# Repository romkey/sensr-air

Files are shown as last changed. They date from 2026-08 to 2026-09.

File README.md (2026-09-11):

# sensr-air








Hardware design and test firmware for a small air quality sensor PCB with:

| Sensor | Function | I2C address |
|---|---|---|
| Sensirion SGP41 | VOC index / NOx index | 0x59 |
| Sensirion STCC4 | CO2 | 0x64 (0x65 if ADDR is high) |
| Sensirion SFA40 | formaldehyde (HCHO) | 0x5D |
| Sensirion SHT40 | temperature / humidity | none — connected to the STCC4's private I2C bus and read through the STCC4 |
| Bosch BMV080 | PM1 / PM2.5 / PM10 | 0x54 |

Boards up to `hw/air-stcc4/0.3.0` carry an SGP40 (VOC only) instead of the
SGP41 and have no SFA40. The two SGP parts share address 0x59; the test
firmwares read the SGP4x feature set at startup to tell them apart, so one
build runs on either revision.

This is a 3.3 V board with no voltage regulator — don't use it with 5 V
circuits. To simplify it, the board is opinionated about I2C
addresses and doesn't expose address selection pins for chips that
have them. For reliability I don't recommend putting too many chips on
one I2C bus.

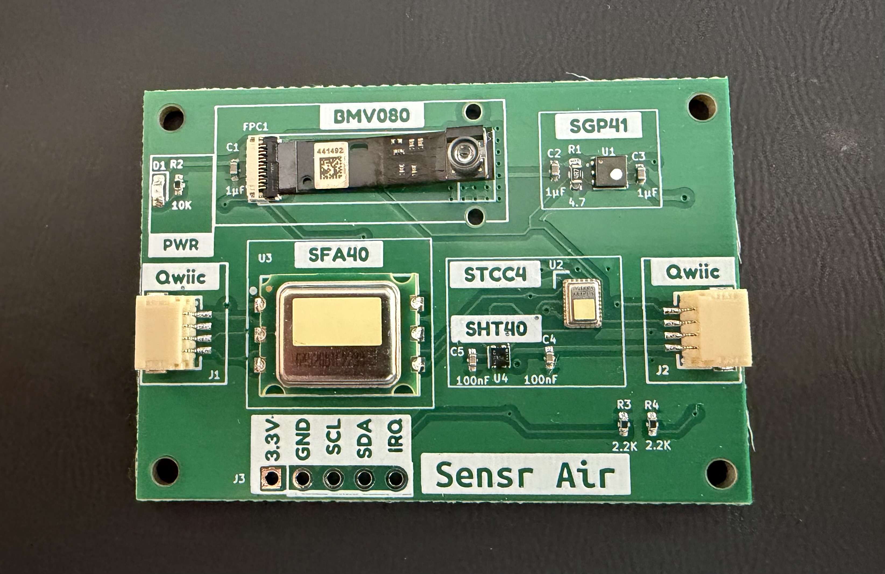
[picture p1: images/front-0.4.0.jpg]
front
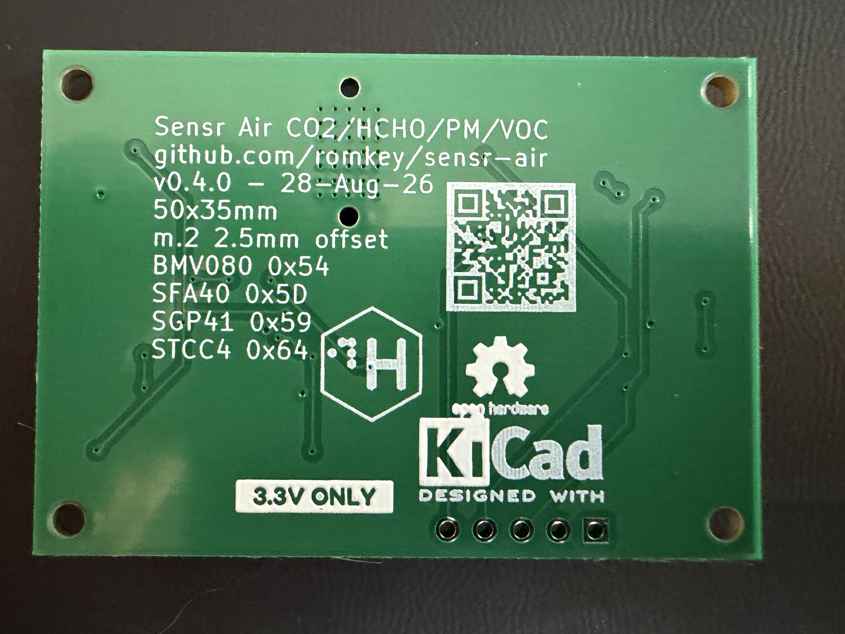
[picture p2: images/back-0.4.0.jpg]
back
 

## AI Disclosure

The board was designed by a human. CI and firmware were generated by AI.

## Hardware

Board designs live under [hw/](hw/), one subdirectory per board with a
subdirectory per version:

- [hw/air-stcc4/](hw/air-stcc4/) — STCC4 + SHT40 breakout
- [hw/air/](hw/air/) — earlier SCD40 + BME680 board

### KiCAD CI

The [KiCAD workflow](.github/workflows/kicad.yml) runs
[ci/kicad-check.sh](ci/kicad-check.sh), which runs ERC on every schematic and
DRC on every PCB of the latest version of each board under `hw/`. Only errors
fail the check; warnings are ignored. Boards or versions containing a
`.ci-kicad-ignore` file are skipped.

Run it locally with KiCAD 8+ installed:

```sh
./ci/kicad-check.sh
```

### kilint CI

The [kilint workflow](.github/workflows/kilint.yml) runs
[kilint](https://github.com/romkey/kilint), a linter for KiCAD project
conventions that ERC and DRC don't cover (title blocks, reference designators,
mounting holes, part number fields, net classes, and so on). It runs only when
[BOFFF.md](BOFFF.md) is present, and lints the single board that BOFFF.md's
`repository_path` points at via [ci/kilint-check.sh](ci/kilint-check.sh).
Older boards under `hw/` predate these conventions and are not checked.

Rule configuration lives in [.kilint.yml](.kilint.yml). kilint has no tagged
releases yet, so the workflow installs it from `main`; pin `KILINT_REF` in the
workflow once it does.

Run it locally:

```sh
pip install git+https://github.com/romkey/kilint
./ci/kilint-check.sh
```

### BOFFF

[BOFFF.md](BOFFF.md) is this board's machine-readable fabrication/form-factor
description (Bill of Form, Fit and Features) - it's a tldr; for
important facts about the board. The [BOFFF workflow](.github/workflows/bofff.yml) does nothing but
assert the file exists, so the BOFFF badge above is green whenever the repo
carries one.

## Test firmware

Each firmware directory contains a test program that exercises all of the
board's sensors, a README, and (where possible) a docker compose file to
build it. All of them print/report readings from each sensor so you can
verify a freshly assembled board.

| Directory | Platform | SGP41 | STCC4 | SFA40 | SHT40 (via STCC4) | BMV080 |
|---|---|---|---|---|---|---|
| [firmware/circuitpython/](firmware/circuitpython/) | CircuitPython 9+ | yes | yes | yes³ | yes | presence check only¹ |
| [firmware/arduino/](firmware/arduino/) | Arduino / ESP32 | yes | yes | yes | yes | yes |
| [firmware/esphome/](firmware/esphome/) | ESPHome / ESP32 | yes | yes² | yes⁴ | yes² | yes |

¹ Bosch only ships the BMV080 driver as closed-source precompiled static
libraries for specific MCU toolchains, so no CircuitPython driver exists.

² ESPHome has no upstream STCC4 support; this repo includes a local
[external component](firmware/esphome/components/stcc4/) for it.

³ Via [romkey/circuitpython-sfa40](https://github.com/romkey/circuitpython-sfa40).

⁴ ESPHome's `sfa40` component landed upstream after 2026.8, so the ESPHome
build uses the beta channel until a stable release includes it.

CI builds all three firmwares on every push
([CircuitPython](.github/workflows/circuitpython.yml),
[Arduino](.github/workflows/arduino.yml),
[ESPHome](.github/workflows/esphome.yml)).

## License

Hardware designs are licensed under the
[CERN Open Hardware Licence v2 Permissive](https://ohwr.org/cern_ohl_p_v2.txt).
Firmware is licensed under the [MIT License](https://opensource.org/license/mit).

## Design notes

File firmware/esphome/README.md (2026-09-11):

# ESPHome Test Firmware

Test firmware for the sensr-air board sensors as an ESPHome configuration,
targeting ESP32-S3 (adjust `board` and I2C pins in `sensor-test.yaml` for
your dev board).

## What it tests

| Sensor | Address | Component | Coverage |
|---|---|---|---|
| SGP41 (VOC/NOx) | 0x59 | native [`sgp4x`](https://esphome.io/components/sensor/sgp4x/) platform | VOC index + NOx index |
| STCC4 (CO2) | 0x64 | local external component ([components/stcc4](components/stcc4/)) | CO2 readings |
| SFA40 (HCHO) | 0x5D | native `sfa40` platform (ESPHome 2026.9+) | formaldehyde, temp/RH |
| SHT40 (temp/RH) | (via STCC4) | local external component | temp/RH read through the STCC4 |
| BMV080 (PM) | 0x54 | [sweitzja/esphome-bmv080](https://github.com/sweitzja/esphome-bmv080) | PM1 / PM2.5 / PM10, obstruction |

The SHT40 is not directly reachable on the I2C bus — it sits on the STCC4's
private second I2C bus, and the STCC4 reports its temperature and humidity
values as part of its measurement data.

The SFA40 measures its own temperature and humidity and uses them to
compensate the formaldehyde reading, so it reports all three.

### SGP40 or SGP41?

Boards from `hw/air-stcc4/0.4.0` on carry an SGP41 (VOC **and** NOx); earlier
boards carry an SGP40 (VOC only). You don't have to configure which: both
answer at 0x59, and the `sgp4x` component reads the sensor's feature set
(command 0x202F) at startup and logs which part it found. NOx needs an SGP41 —
on an SGP40 the component logs `SGP41 required for NOx, disabling NOx sensor`
and carries on with VOC alone, so this config works on either board.

### ESPHome version

The `sfa40` component was merged upstream after the 2026.8 release, so both
the CI workflow and `docker-compose.yml` build against the ESPHome **beta**
channel. Switch them back to `latest` once a stable release includes it.

ESPHome has no upstream STCC4 support yet, so this directory ships a small
external component in [components/stcc4](components/stcc4/) that starts
continuous measurement and reads CO2, temperature, and humidity using
Sensirion's documented I2C command set.

The BMV080 component wraps Bosch's closed-source precompiled SDK; it supports
ESP32, ESP32-S3, ESP32-C3, and ESP32-C6. It injects the SDK through
PlatformIO build flags, so the config pins `toolchain: platformio` — ESPHome's
native ESP-IDF toolchain (the default since 2026.7) doesn't honor those flags
and the build fails without it.

## Building

```sh
cp secrets.yaml.example secrets.yaml   # then edit with your Wi-Fi credentials
esphome compile sensor-test.yaml
```

Or with docker compose:

```sh
cp secrets.yaml.example secrets.yaml
docker compose run --rm compile
```

## Flashing and logs

```sh
esphome run sensor-test.yaml
```

Or with docker compose (adjust the serial device in `docker-compose.yml` if
needed):

```sh
docker compose run --rm esphome run sensor-test.yaml
```

The log output shows the I2C scan (expect devices at 0x54, 0x59, 0x5D, and
0x64) and periodic readings from all sensors.

If the STCC4's ADDR line is pulled high, change its `address` to `0x65` in
`sensor-test.yaml`.

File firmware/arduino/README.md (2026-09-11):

# Arduino Test Firmware

Test firmware for the sensr-air board sensors, targeting ESP32 boards
(default build target: ESP32-S3).

## What it tests

| Sensor | Address | Library | Coverage |
|---|---|---|---|
| SGP41 (VOC/NOx) | 0x59 | [Sensirion I2C SGP41](https://github.com/Sensirion/arduino-i2c-sgp41) | self test + raw VOC and NOx signals |
| STCC4 (CO2) | 0x64 | [Sensirion I2C STCC4](https://github.com/Sensirion/arduino-i2c-stcc4) | self test + CO2 readings |
| SFA40 (HCHO) | 0x5D | [Sensirion I2C SFA4x](https://github.com/Sensirion/arduino-i2c-sfa4x) | serial number + formaldehyde, temp/RH |
| SHT40 (temp/RH) | (via STCC4) | [Sensirion I2C STCC4](https://github.com/Sensirion/arduino-i2c-stcc4) | temp/RH read through the STCC4 |
| BMV080 (PM) | 0x54 | [DFRobot_BMV080](https://github.com/DFRobot/DFRobot_BMV080) | PM1 / PM2.5 / PM10 readings |

The SHT40 is not directly reachable on the I2C bus — it sits on the STCC4's
private second I2C bus, and the STCC4 reports its temperature and humidity
values as part of its measurement data.

### SGP40 or SGP41?

Boards from `hw/air-stcc4/0.4.0` on carry an SGP41 (VOC **and** NOx); earlier
boards carry an SGP40 (VOC only). Both answer at 0x59 and both respond to the
same serial-number command, so the sketch tells them apart the only way you
can: by issuing the SGP4x "Get Feature Set" command (0x202F) and masking the
low 9 bits of the reply — `0x0020` is an SGP40, `0x0040` an SGP41. The sketch
prints which part it found and drives it with the matching Sensirion library,
so one build works on either board.

The SGP41 needs up to 10 seconds of NOx conditioning at 1 Hz after power-up;
`SRAW_NOx` reads 0 until that finishes, and the sketch marks those lines
`(conditioning)`.

The SFA40's self-test puts the sensor into a special mode for 5–6 minutes, so
the sketch doesn't run it — it reads the serial number and starts continuous
measurement instead.

The BMV080 driver is Bosch's closed-source precompiled SDK, bundled in the
DFRobot library. It only supports Xtensa ESP32 targets (ESP32, ESP32-S2,
ESP32-S3), which is why this sketch targets ESP32.

## Wiring

Connect the sensr-air board to your ESP32 via the Qwiic/STEMMA QT connector,
or wire 3V3, GND, SDA, and SCL to the board's header. This is a 3.3 V board —
do not use 5 V.

The sketch uses the dev board's default `SDA`/`SCL` pins. To override, define
`I2C_SDA_PIN` / `I2C_SCL_PIN` at build time or edit the top of the sketch.

If the STCC4's ADDR line is pulled high, change `STCC4_ADDR` to `0x65`.

## Building with arduino-cli

```sh
arduino-cli config init --additional-urls \
    https://espressif.github.io/arduino-esp32/package_esp32_index.json
arduino-cli core update-index
arduino-cli core install esp32:esp32

arduino-cli lib install "Sensirion Core" "Sensirion I2C SGP40" \
    "Sensirion I2C SGP41" "Sensirion I2C SFA4x" "Sensirion I2C STCC4"
arduino-cli config set library.enable_unsafe_install true
arduino-cli lib install --git-url https://github.com/DFRobot/DFRobot_BMV080.git

arduino-cli compile --fqbn esp32:esp32:esp32s3 sensor-test
arduino-cli upload --fqbn esp32:esp32:esp32s3 -p /dev/ttyACM0 sensor-test
```

## Building with docker compose

```sh
docker compose run --rm build
```

The compiled firmware is written to `./build/`. Flash it with `esptool` or
`arduino-cli upload`.

## Expected output

PASS/FAIL lines for each sensor on the serial console (115200 baud), then
continuous readings every 2 seconds:

```
[PASS] SGP4x present (0x59) detected: SGP41
[PASS] STCC4 present (0x64)
[PASS] SFA40 present (0x5D)
[PASS] BMV080 present (0x54)

[PASS] SGP41 self test result: 0xd400
[PASS] STCC4 self test
[PASS] SFA40 init serial: ...
[PASS] BMV080 init id: ...

SGP41:  raw VOC 30398, raw NOx 15803
STCC4:  CO2 617 ppm | SHT40: 23.4 C, 41.2 %RH
SFA40:  HCHO 12.3 ppb | 23.6 C, 40.8 %RH (status 0x0000)
BMV080: PM1 2.1, PM2.5 3.4, PM10 4.0 ug/m3
```

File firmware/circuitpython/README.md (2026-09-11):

# CircuitPython Test Firmware

Test firmware for the sensr-air board sensors, written for CircuitPython 9+.

## What it tests

| Sensor | Address | Driver | Coverage |
|---|---|---|---|
| SGP41 (VOC/NOx) | 0x59 | [adafruit_sgp41](https://github.com/adafruit/Adafruit_CircuitPython_SGP41) | self test + raw signals + VOC/NOx index |
| STCC4 (CO2) | 0x64 | [adafruit_stcc4](https://github.com/adafruit/Adafruit_CircuitPython_STCC4) | self test + CO2 readings |
| SFA40 (HCHO) | 0x5D | [sfa40](https://github.com/romkey/circuitpython-sfa40) | serial number + formaldehyde, temp/RH |
| SHT40 (temp/RH) | (via STCC4) | [adafruit_stcc4](https://github.com/adafruit/Adafruit_CircuitPython_STCC4) | temp/RH read through the STCC4 |
| BMV080 (PM) | 0x54 | none | I2C presence check only |

The SHT40 is not directly reachable on the I2C bus — it sits on the STCC4's
private second I2C bus, and the STCC4 reports its temperature and humidity
values as part of its measurement data.

### SGP40 or SGP41?

Boards from `hw/air-stcc4/0.4.0` on carry an SGP41 (VOC **and** NOx); earlier
boards carry an SGP40 (VOC only). Both answer at 0x59 and both respond to the
same serial-number command, so the code tells them apart the only way you can:
by reading the SGP4x "Get Feature Set" command (0x202F) and masking the low 9
bits of the reply — `0x0020` is an SGP40, `0x0040` an SGP41. This is exactly
what ESPHome's `sgp4x` component does. The test prints which part it found and
loads the matching driver, so the same `code.py` works on either board.

The SGP41 needs up to 10 seconds of NOx conditioning at 1 Hz after power-up
before its first real measurement, which the test runs before it starts
printing readings. The gas index algorithm then warms up for about 45 seconds,
returning 0 for both indices until it settles.

**SFA40 self test:** the SFA40's self-test puts the sensor into a special mode
for 5–6 minutes, so this test doesn't run it. Use the driver's
`sfa40_self_test.py` example if you want to run it after assembly.

**BMV080 limitation:** Bosch only distributes the BMV080 driver as
closed-source precompiled static libraries for specific MCU toolchains, so no
CircuitPython driver exists. This test only verifies the BMV080 answers on the
I2C bus at 0x54. Use the [Arduino](../arduino/) or [ESPHome](../esphome/)
tests for actual PM readings.

## Running on hardware

1. Install CircuitPython 9+ on a board with a STEMMA QT/Qwiic connector (or
   wire the sensr-air board's SDA/SCL/3V3/GND to your board's I2C pins).
   The code prefers `board.STEMMA_I2C()` and falls back to
   `board.SCL`/`board.SDA`.
2. Install the Adafruit libraries onto the board with
   [circup](https://github.com/adafruit/circup):

   ```sh
   circup install adafruit_sgp41 adafruit_stcc4
   ```

   Add `adafruit_sgp40` too if you are testing a board older than 0.4.0.
   The SFA40 driver isn't in the Adafruit bundle, so copy its `sfa40.py` to
   the `lib` directory on the `CIRCUITPY` drive:

   ```sh
   git clone https://github.com/romkey/circuitpython-sfa40
   cp circuitpython-sfa40/sfa40.py /Volumes/CIRCUITPY/lib/
   ```

3. Copy `code.py` to the `CIRCUITPY` drive.
4. Watch the serial console. You should see PASS lines for each sensor
   followed by continuous readings every 2 seconds.

If the STCC4's ADDR line is pulled high, change `STCC4_ADDR` to `0x65` at the
top of `code.py`.

## Build check

CircuitPython is interpreted, so the "build" is a compile check with
`mpy-cross` (this is what CI runs):

```sh
pip install mpy-cross
mpy-cross code.py -o /tmp/code.mpy
```

Or with docker compose:

```sh
docker compose run --rm build
```

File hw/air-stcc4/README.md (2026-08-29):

# Sensr Air STCC4

This breakout board has Sensirion's new CO2 sensor, the STCC4, as well as an SHT40 temperature/humidity sensor. The board also has two STEMMAQT/Qwiic connectors and a five pin header with power, I2C and the STCC4's address select pin.

This is a 3.3V board and has no voltage regulator, so don't use it with 5V circuits!

It also has a power LED.

The STCC4 has a selectable I2C address depending on the state of the ADDR line.  The ADDR line has a weak pulldown resistor so that the STCC4's default I2C address is 0x64. If ADDR is high, the address will be 0x65.

The SHT40 is not directly accessible from the I2C bus. Instead it connects to a private second I2C bus with the STCC4. Its values may be read through the STCC4.

## 0.1.0 Hardware

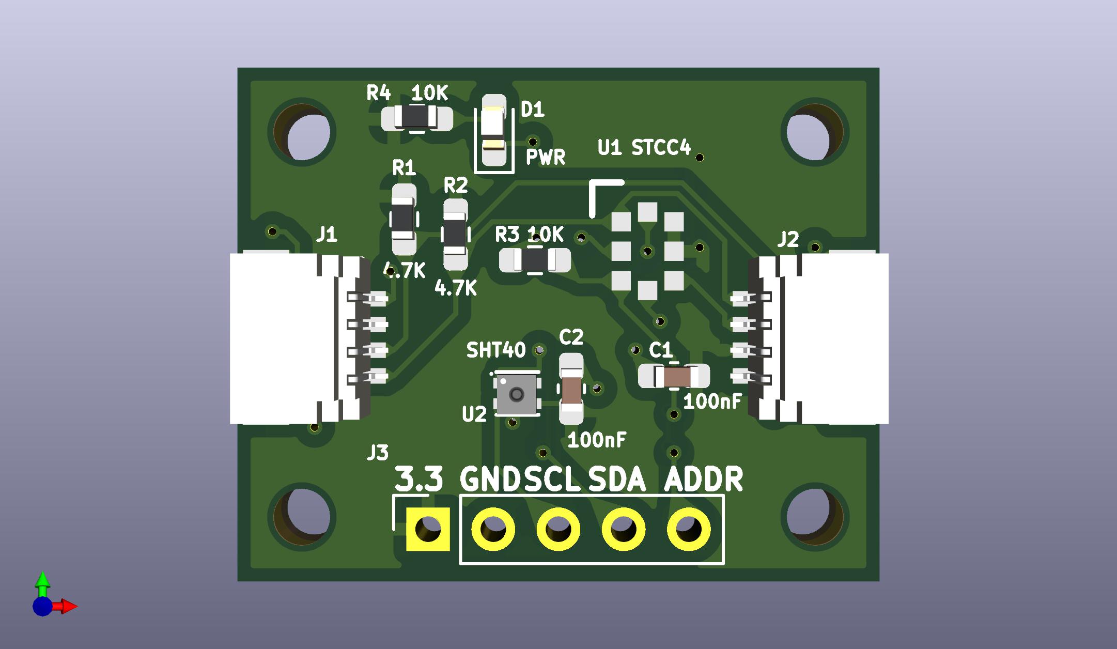
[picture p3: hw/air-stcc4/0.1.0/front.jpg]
front


## Firmware

Example program in CircuitPython:

```
import time
import board
import busio
from adafruit_stcc4 import STCC4

# Initialize I2C bus
i2c = busio.I2C(board.SCL, board.SDA)

# Initialize STCC4 sensor
sensor = STCC4(i2c)

print("STCC4 CO2 Sensor Test")
print("=" * 50)

# Print sensor information
print(f"Serial Number: {sensor.serial_number}")
print(f"Firmware Version: {sensor.firmware_version[0]}.{sensor.firmware_version[1]}")
print(f"SHT40 Available: {sensor.sht40_available}")
print()

# Read CO2, temperature, and humidity measurements
print("Environmental Measurements:")
print("-" * 30)

while True:
    co2 = sensor.co2
    print(f"Reading {i+1:2d}: CO2: {co2:6.1f} ppm")
        
    if sensor.sht40_available:
       temperature, humidity = sensor.measure_temperature_humidity()
       print(f"           Temp: {temperature:5.1f}°C, Humidity: {humidity:5.1f}%")
    else:
       print("           SHT40 not available - no temp/humidity data")
        
    print()
        
    time.sleep(2)  # Wait 2 seconds between readings

print("Test complete!")
```

## License

Please see the top level [README](../../README.md) for license information.

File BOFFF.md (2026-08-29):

---
bofff_version: 1
board:
  name: Sensr Air CO2/HCHO/PM/VOC
  version: 0.4.0
  date: '2026-08-28'
  organization: PDX Hackerspace
  license: CERN-OHL-S
  repository: https://github.com/romkey/sensr-air
  repository_path: hw/air-stcc4/0.4.0
  notes:
  - John Romkey
  - 'License: CERN-OHL-S https://ohwr.org/cern_ohl_s_v2.pdf'
source_files:
  ecad: KiCad
  project: air-stcc4.kicad_pro
  schematic: air-stcc4.kicad_sch
  pcb: air-stcc4.kicad_pcb
  step: null
  dxf: null
  bom: null
form:
  units: mm
  origin: top-left of bounding box, x right, y down
  outline:
    shape: rectangle
    width: 50
    height: 35
  thickness: 1.6
  copper_layers: 2
  max_height_top: null
  max_height_bottom: null
mounting:
  holes:
  - ref: MNT1
    x: 2.5
    y: 2.5
    diameter: 2.2
  - ref: MNT2
    x: 47.5
    y: 2.5
    diameter: 2.2
  - ref: MNT3
    x: 2.5
    y: 32.5
    diameter: 2.2
  - ref: MNT4
    x: 47.5
    y: 32.5
    diameter: 2.2
power:
  rails:
  - net: GND
    kind: ground
    connections: 14
  - net: +3.3V
    kind: supply
    connections: 16
  usb:
    present: false
  battery:
    present: false
  input_voltage: null
  current_typical: null
  current_peak: null
connectors:
- ref: FPC1
  part: 046844713002846+_C5857733
  footprint: easyeda2kicad:FPC-SMD_13P-P0.60_046844713002846-1
  x: 10.555
  y: 7.124
  populated: true
  pins:
  - pad: '2'
    net: /BV_IRQ
  - pad: '3'
    net: GND
  - pad: '4'
    net: +3.3V
  - pad: '5'
    net: GND
  - pad: '6'
    net: +3.3V
  - pad: '7'
    net: +3.3V
  - pad: '8'
    net: /SCL
  - pad: '9'
    net: /SDA
  - pad: '10'
    net: GND
  - pad: '11'
    net: +3.3V
  - pad: '12'
    net: GND
  - pad: '13'
    net: +3.3V
  - pad: '14'
    net: GND
  - pad: '15'
    net: GND
- ref: J1
  part: BM04B-SRSS-TB(LF)(SN)
  footprint: easyeda2kicad:CONN-SMD_4P-P1.00_SM04B-SRSS-TB-LF-SN
  x: 3.5
  y: 21
  populated: true
  pins:
  - pad: '1'
    net: GND
  - pad: '2'
    net: +3.3V
  - pad: '3'
    net: /SDA
  - pad: '4'
    net: /SCL
  - pad: '5'
    net: GND
  - pad: '6'
    net: GND
- ref: J2
  part: BM04B-SRSS-TB(LF)(SN)
  footprint: easyeda2kicad:CONN-SMD_4P-P1.00_SM04B-SRSS-TB-LF-SN
  x: 46.31
  y: 21
  populated: true
  pins:
  - pad: '1'
    net: GND
  - pad: '2'
    net: +3.3V
  - pad: '3'
    net: /SDA
  - pad: '4'
    net: /SCL
  - pad: '5'
    net: GND
  - pad: '6'
    net: GND
- ref: J3
  part: Conn_01x08
  footprint: Connector_PinSocket_2.54mm:PinSocket_1x05_P2.54mm_Vertical
  x: 11.42
  y: 33
  populated: false
  pins:
  - pad: '1'
    net: +3.3V
  - pad: '2'
    net: GND
  - pad: '3'
    net: /SCL
  - pad: '4'
    net: /SDA
  - pad: '5'
    net: /BV_IRQ
interfaces:
  i2c:
  - name: primary
    nets:
    - /SCL
    - /SDA
    pullups:
    - ref: R4
      line: SCL
      net: /SCL
      pulls_to: +3.3V
      voltage: 3.3
      value: 2.2K
      resistance: 2200
    - ref: R3
      line: SDA
      net: /SDA
      pulls_to: +3.3V
      voltage: 3.3
      value: 2.2K
      resistance: 2200
    devices:
    - ref: U1
      part: SGP41
      address: '0x59'
    - ref: U2
      part: STCC4
      address: '0x64'
    - ref: U3
      part: SFA40-D-R1
      address: '0x5D'
    exposed_on:
    - FPC1
    - J1
    - J2
    - J3
  - name: _c
    nets:
    - /SCL_C
    - /SDA_C
    pullups: null
    devices:
    - ref: U2
      part: STCC4
      address: '0x64'
    - ref: U4
      part: SHT40
      address: '0x44'
    exposed_on: null
---

# Sensr Air CO2/HCHO/PM/VOC — BOFFF

**BOFFF** — a Bill Of Form, Fit and Function. A summary of this
board's physical and electrical facts for anyone designing an
enclosure, a mount, or a mating board.

- **Form** — outline, thickness, layer count.
- **Fit** — mounting holes and connector positions.
- **Function** — power rails and the buses the board exposes.

## Coordinates

Millimetres. The origin is the **top-left corner of the board
outline's bounding box**, with X increasing right and Y increasing
**down**. This is the opposite of the usual mathematical
convention and is the most likely source of a silent error in
anything consuming this file.

## Generated, not authored

Everything above was extracted from the KiCad files listed under
`source_files`. Regenerate it rather than editing it by hand:

```bash
kilint bofff . > BOFFF.md
```

For exact geometry — curves, slots, internal cutouts, component
heights — use the STEP/DXF exports rather than this summary. A
bounding box is not an outline.

## Complete by hand

These are not recorded in the KiCad files and are emitted as
`null`. They need a human:

- `form.max_height_top` — tallest component above the board; from the 3D models, not the PCB
- `form.max_height_bottom` — tallest component below the board; same
- `power.input_voltage` — the operating range; the netlist does not say
- `power.current_typical` — a measurement
- `power.current_peak` — a measurement
- `source_files.step` — path to the 3D export, once you make one
- `source_files.dxf` — path to the 2D outline export, once you make one
- `source_files.bom` — path to the exported BOM

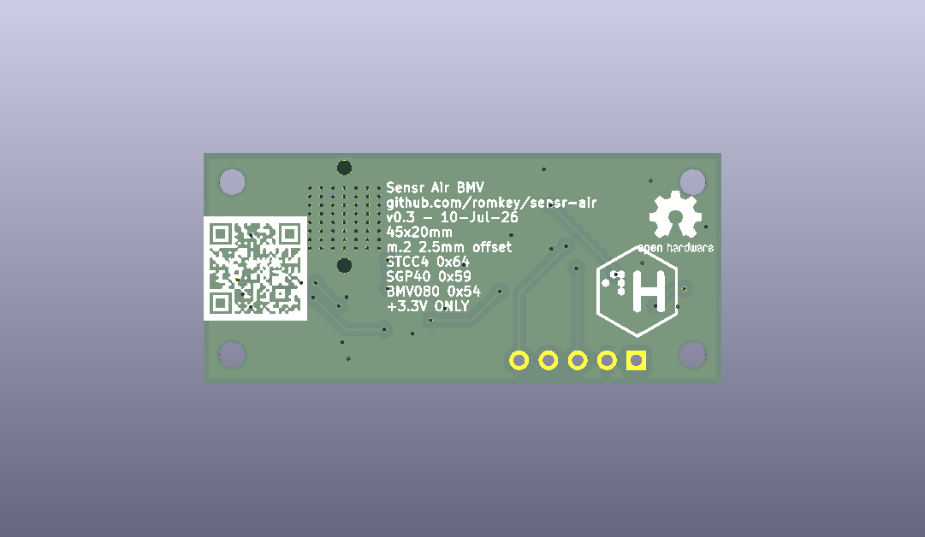
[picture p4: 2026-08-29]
images/back.png

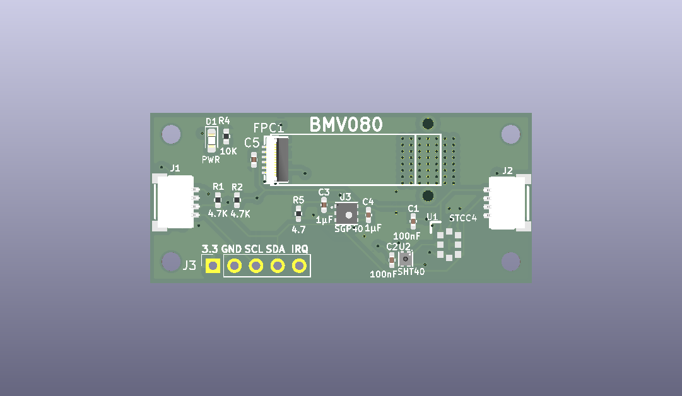
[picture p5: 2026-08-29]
images/front.png

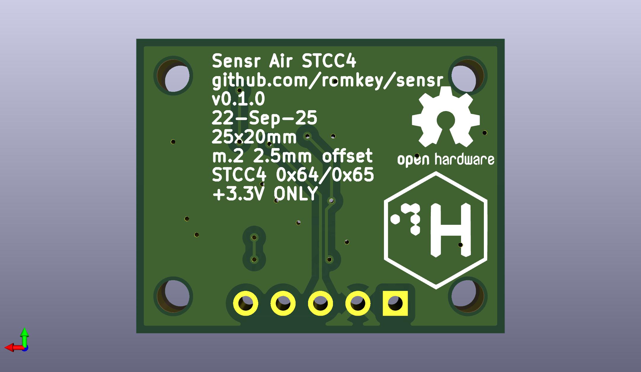
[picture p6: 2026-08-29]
hw/air-stcc4/0.1.0/back.jpg

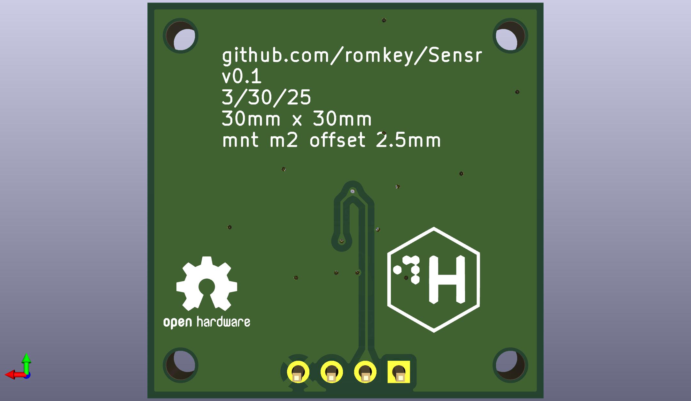
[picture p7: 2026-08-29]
hw/air/0.2/back.jpg

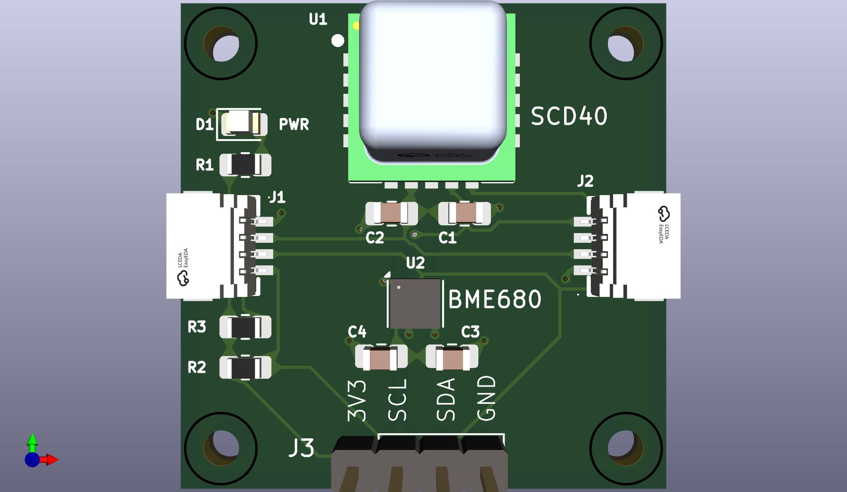
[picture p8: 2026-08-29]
hw/air/0.2/front.jpg

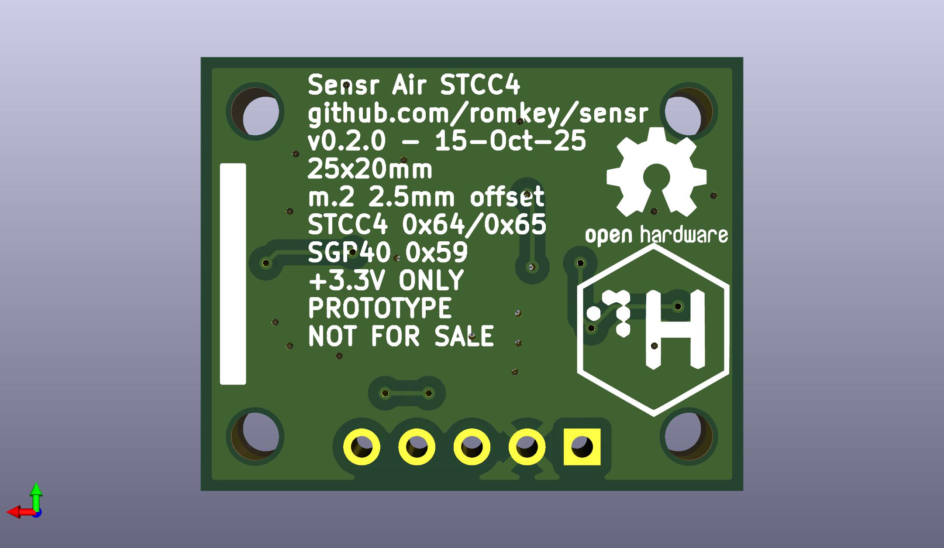
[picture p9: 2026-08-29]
hw/air-stcc4/0.2.0/back.jpg

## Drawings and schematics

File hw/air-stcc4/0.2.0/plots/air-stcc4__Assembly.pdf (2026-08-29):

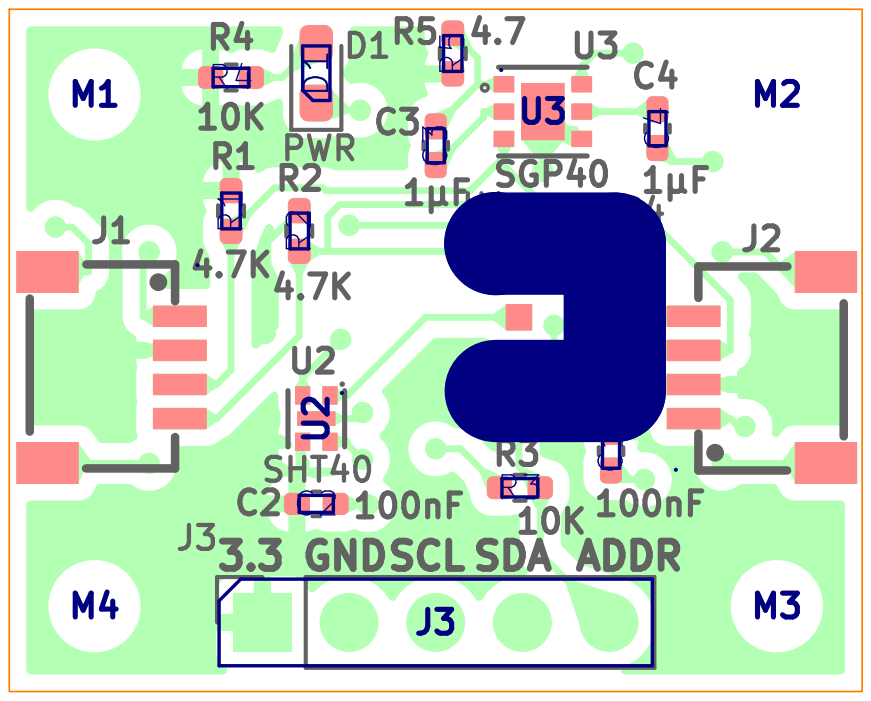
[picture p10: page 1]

Id: /1 Title: Sensr Air STCC4

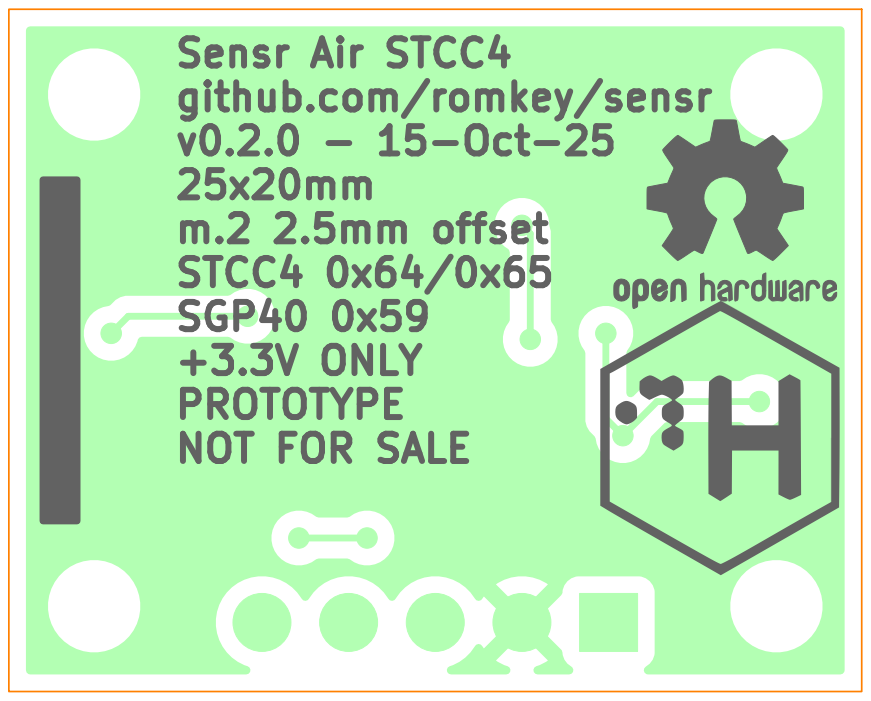
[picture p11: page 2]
Sensr Air STCC4 github.com/romkey/sensr v0.2.0 -; 15-Oct-25; m.2 2.5mm offset STCC4 0x64/0x65 SGP40 0x59 +3.3V; ONLY; PROTOTYPE NOT FOR SALE 1; D Date: 2025-10-15 KiCad; E.D.A. 9.0.4 Size: A4; Rev: 0.2.0; File: air-stcc4.kicad_pcb Sheet: Colored; BOT PDX; Hackerspace; John; Romkey License: CERN-OHL-S; https://ohwr.org/cern_ohl_s_v2.pdf PROTOTYPE -; NOT; FOR SALE; Board2Pdf:; Colored; BOT -; Page 2/2

Id: /1 Title: Sensr Air STCC4

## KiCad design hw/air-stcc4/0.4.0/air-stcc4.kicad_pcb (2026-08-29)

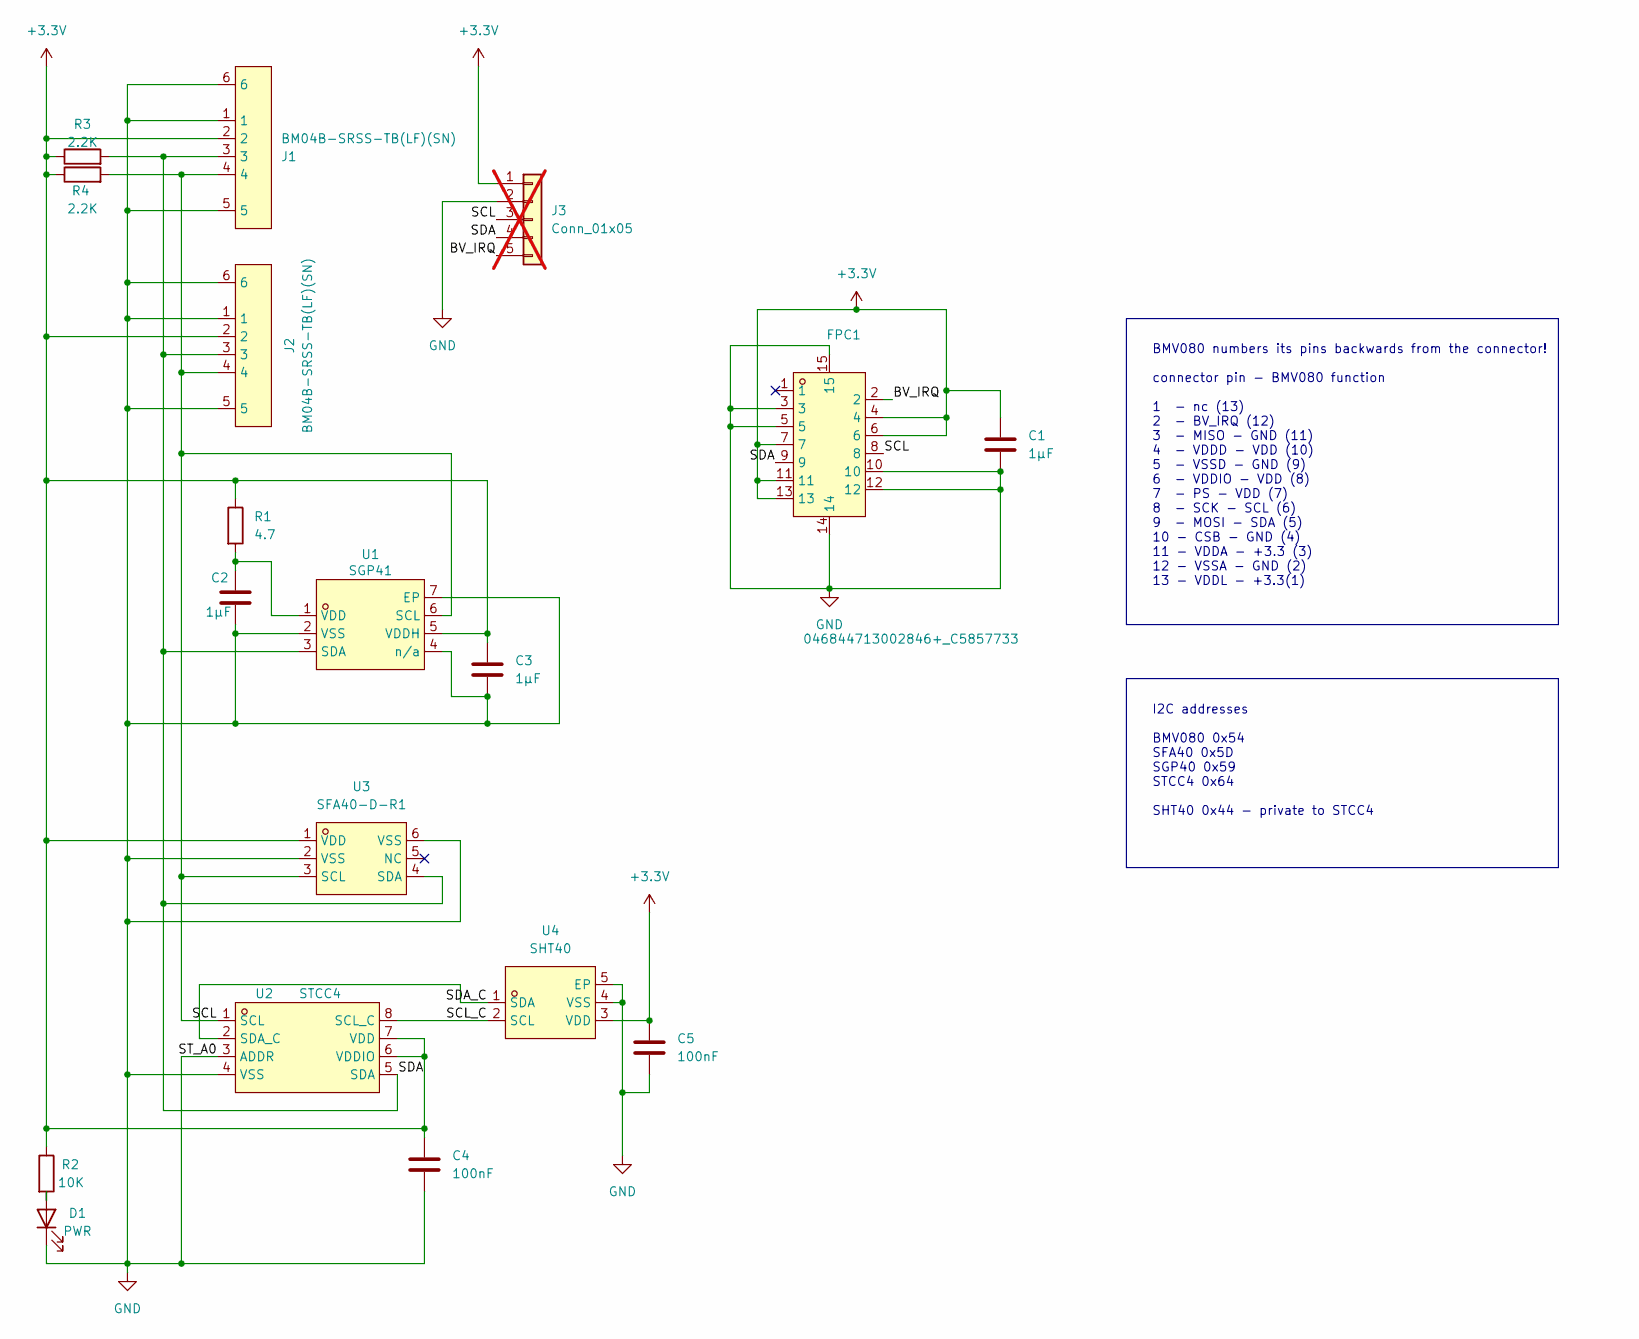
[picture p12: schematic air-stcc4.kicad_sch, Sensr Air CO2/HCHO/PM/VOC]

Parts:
C1, C2, C3: 1µF; C_0402_1005Metric_Pad0.74x0.62mm_HandSolder; LCSC Part C52923
C4, C5: 100nF; C_0402_1005Metric_Pad0.74x0.62mm_HandSolder; LCSC Part C1525
D1: PWR; LED_0603_1608Metric_Pad1.05x0.95mm_HandSolder; LCSC Part C2286
FPC1: 046844713002846+_C5857733; FPC-SMD_13P-P0.60_046844713002846-1; LCSC Part C5857733
J1, J2: BM04B-SRSS-TB(LF)(SN); CONN-SMD_4P-P1.00_SM04B-SRSS-TB-LF-SN; LCSC Part C160404
J3: Conn_01x05; PinSocket_1x05_P2.54mm_Vertical; not fitted
R1: 4.7; R_0603_1608Metric_Pad0.98x0.95mm_HandSolder; LCSC Part C23164
R2: 10K; R_0402_1005Metric_Pad0.72x0.64mm_HandSolder; LCSC Part C25744
R3, R4: 2.2K; R_0402_1005Metric_Pad0.72x0.64mm_HandSolder; LCSC Part C25879
U1: SGP41; DFN-6_L2.4-W2.4-P0.80-TL-EP; LCSC Part C3659325
U2: STCC4; LAG-8_L4.0-W3.0-P1.15-TL; LCSC Part C49191471
U3: SFA40-D-R1; SENSOR-SMD_SFA40-D-R1; LCSC Part C54863645
U4: SHT40; DFN-4_L1.5-W1.5-P0.80-TL-EP; LCSC Part C2848306

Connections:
+3.3V: C1.1, C3.1, C4.1, C5.1, FPC1.4, FPC1.6, FPC1.7, FPC1.11, FPC1.13, J1.2, J2.2, J3.1, R1.1, R2.1, R3.1, R4.1, U1.5 (VDDH), U2.6 (VDDIO), U2.7 (VDD), U3.1 (VDD), U4.3 (VDD)
/BV_IRQ: FPC1.2, J3.5
/SCL: FPC1.8, J1.4, J2.4, J3.3, R4.2, U1.6 (SCL), U2.1 (SCL), U3.3 (SCL)
/SCL_C: U2.8 (SCL_C), U4.2 (SCL)
/SDA: FPC1.9, J1.3, J2.3, J3.4, R3.2, U1.3 (SDA), U2.5 (SDA), U3.4 (SDA)
/SDA_C: U2.2 (SDA_C), U4.1 (SDA)
GND: C1.2, C2.2, C3.2, C4.2, C5.2, D1.1 (K), FPC1.3, FPC1.5, FPC1.10, FPC1.12, FPC1.14, FPC1.15, J1.1, J1.5, J1.6, J2.1, J2.5, J2.6, J3.2, U1.2 (VSS), U1.4 (n/a), U1.7 (EP), U2.3 (ADDR), U2.4 (VSS), U3.2 (VSS), U3.6 (VSS), U4.4 (VSS), U4.5 (EP)
unnamed: D1.2 (A), R2.2
unnamed: C2.1, R1.2, U1.1 (VDD)

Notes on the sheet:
BMV080 numbers its pins backwards from the connector! connector pin - BMV080 function 1 - nc (13) 2 - BV_IRQ (12) 3 - MISO - GND (11) 4 - VDDD - VDD (10) 5 - VSSD - GND (9) 6 - VDDIO - VDD (8) 7 - PS - VDD (7) 8 - SCK - SCL (6) 9 - MOSI - SDA (5) 10 - CSB - GND (4) 11 - VDDA - +3.3 (3) 12 - VSSA - 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
I2C addresses BMV080 0x54 SFA40 0x5D SGP40 0x59 STCC4 0x64 SHT40 0x44 - private to STCC4

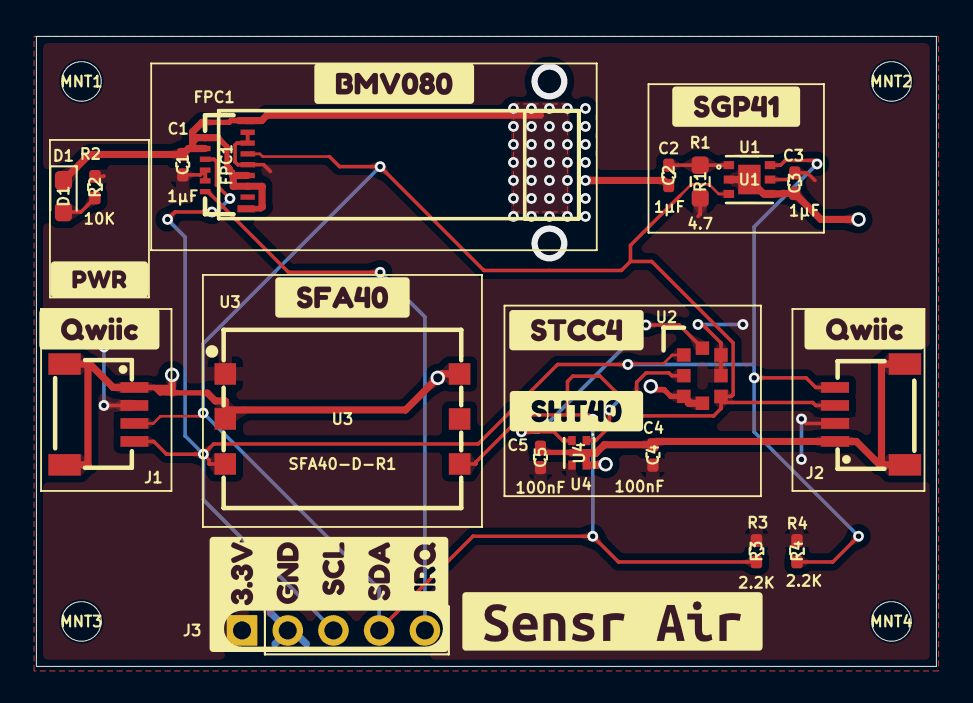
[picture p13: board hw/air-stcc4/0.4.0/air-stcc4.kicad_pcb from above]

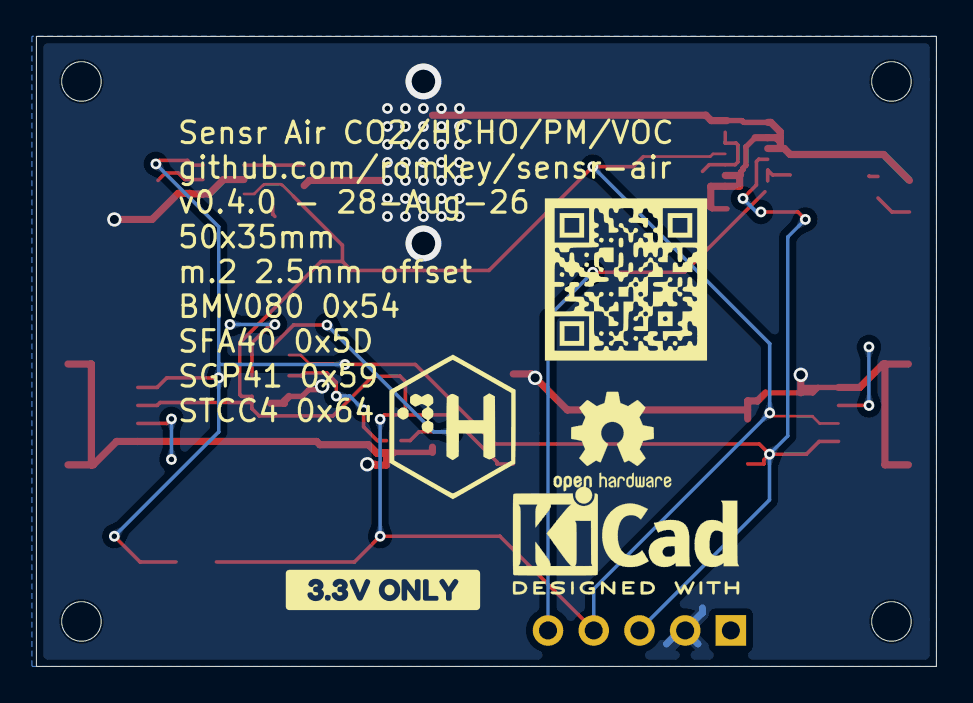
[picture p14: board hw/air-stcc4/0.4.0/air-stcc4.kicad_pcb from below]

Board: 2 copper layers, 50.0 x 35.0 mm, 37 parts (5 on the bottom side), 9 nets.

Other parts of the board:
GRPH1: LOGO
GRPH2: CTRLH Logo
GRPH3: OSHW-Logo2_7.3x6mm_SilkScreen
GRPH4: KiCad-Logo2_5mm_SilkScreen
MNT1, MNT2, MNT3, MNT4: MountingHole_2.2mm_M2
kobee-studio-1: GRPH4; kobee-studio-6A887D6C
kobee-studio-2: GRPH5; kobee-studio-6A887DEC
kobee-studio-3: G***; kobee-studio-6A91A728
kobee-studio-4: GRPH8; kobee-studio-6A887E41
kobee-studio-5: GRPH7; kobee-studio-6A887E5F
kobee-studio-6: GRPH9; kobee-studio-6A887E13
kobee-studio-6A91B03A: G***; kobee-studio-6A91B03A
kobee-studio-7: GRPH6; kobee-studio-6A8882DF
kobee-studio-8: GRPH10; kobee-studio-6A887E32
kobee-studio-9: G***; kobee-studio-6A91A7CE
kobee-studio-10: GRPH11; kobee-studio-6A887EAF

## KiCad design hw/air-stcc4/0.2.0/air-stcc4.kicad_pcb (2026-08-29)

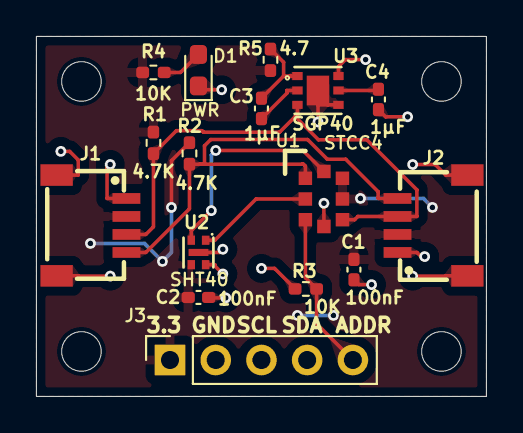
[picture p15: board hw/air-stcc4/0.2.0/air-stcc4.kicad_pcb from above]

Board: 2 copper layers, 25.0 x 20.0 mm, 21 parts (1 on the bottom side), 11 nets.

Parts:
C1, C2: 100nF; C_0402_1005Metric_Pad0.74x0.62mm_HandSolder
C3, C4: 1µF; C_0402_1005Metric_Pad0.74x0.62mm_HandSolder
D1: PWR; LED_0603_1608Metric_Pad1.05x0.95mm_HandSolder
GRPH1: CTRLH Logo
J1, J2: BM04B-SRSS-TB(LF)(SN); CONN-SMD_4P-P1.00_SM04B-SRSS-TB-LF-SN
J3: Conn_01x05; PinSocket_1x05_P2.54mm_Vertical
M1, M2, M3, M4: MountingHole_2.2mm_M2
R1, R2: 4.7K; R_0402_1005Metric_Pad0.72x0.64mm_HandSolder
R3, R4: 10K; R_0402_1005Metric_Pad0.72x0.64mm_HandSolder
R5: 4.7; R_0402_1005Metric_Pad0.72x0.64mm_HandSolder
U1: STCC4; LAG-8_L4.0-W3.0-P1.15-TL
U2: SHT40; DFN-4_L1.5-W1.5-P0.80-TL-EP
U3: SGP40; DFN-6_L2.4-W2.4-P0.80-TL-EP

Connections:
+3.3V: C1.1, C2.1, J1.2, J2.2, J3.1, R1.1, R2.1, R4.1, R5.1, U1.6 (VDDIO), U1.7 (VDD), U2.3 (VDD)
/ADDR: J3.5, R3.1, U1.3 (ADDR)
/SCL_C: U1.8 (SCL_C), U2.2 (SCL)
/SDA_C: U1.2 (SDA_C), U2.1 (SDA)
GND: C1.2, C2.2, C4.2, D1.1 (K), J1.1, J1.5, J1.6, J2.1, J2.5, J2.6, J3.2, R3.2, U1.4 (VSS), U2.4 (VSS), U2.5 (EP), U3.4 (n/a), U3.6 (SCL), U3.7 (GND)
unnamed: D1.2 (A), R4.2
unnamed: J1.4, J2.4, R2.2, U1.1 (SCL)
unnamed: J1.3, J2.3, R1.2, U1.5 (SDA), U3.3 (SDA)
unnamed: C3.1, R5.2, U3.1 (VDD)
unnamed: C4.1, U3.5 (VDDH)
unnamed: C3.2, U3.2 (VSS)

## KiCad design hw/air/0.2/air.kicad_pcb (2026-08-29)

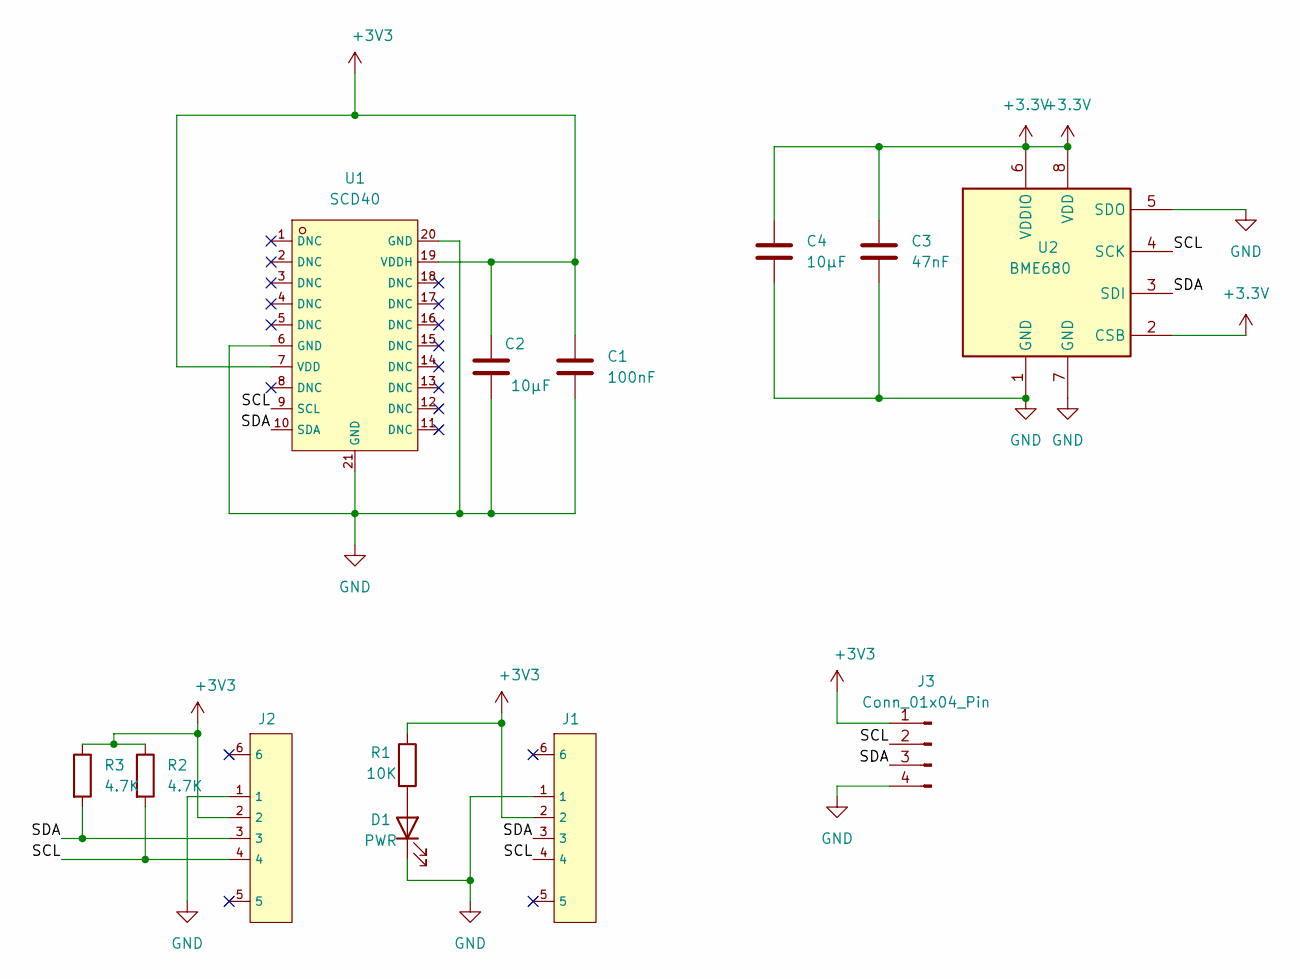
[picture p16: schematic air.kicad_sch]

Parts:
C1: 100nF; C_0805_2012Metric_Pad1.18x1.45mm_HandSolder; MPN C1711
C2, C4: 10µF; C_0805_2012Metric_Pad1.18x1.45mm_HandSolder; MPN C342724
C3: 47nF; C_0805_2012Metric_Pad1.18x1.45mm_HandSolder; MPN C1745
D1: PWR; LED_0805_2012Metric; LCSC C84256
J1, J2: SM04B-SRSS-TB_(LF)(SN); CONN-SMD_4P-P1.00_SM04B-SRSS-TB-LF-SN; LCSC C160404
J3: Conn_01x04_Pin; PinHeader_1x04_P2.54mm_Vertical
R1: 10K; R_0805_2012Metric_Pad1.20x1.40mm_HandSolder; LCSC C17414
R2, R3: 4.7K; R_0805_2012Metric_Pad1.20x1.40mm_HandSolder; MPN C105427
U1: SCD40; LGA-20_L10.1-W10.1-P1.25-TL; LCSC C3659421
U2: BME680; Bosch_LGA-8_3x3mm_P0.8mm_ClockwisePinNumbering; MPN C125972

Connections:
+3.3V: C3.1, C4.1, U2.2 (CSB), U2.6 (VDDIO), U2.8 (VDD)
+3V3: C1.1, C2.1, J1.2, J2.2, J3.1, R1.1, R2.1, R3.1, U1.7 (VDD), U1.19 (VDDH)
/SCL: J1.4, J2.4, J3.2, R2.2, U1.9 (SCL), U2.4 (SCK)
/SDA: J1.3, J2.3, J3.3, R3.2, U1.10 (SDA), U2.3 (SDI)
GND: C1.2, C2.2, C3.2, C4.2, D1.1 (K), J1.1, J2.1, J3.4, U1.6 (GND), U1.20 (GND), U1.21 (GND), U2.1 (GND), U2.5 (SDO), U2.7 (GND)
unnamed: D1.2 (A), R1.2

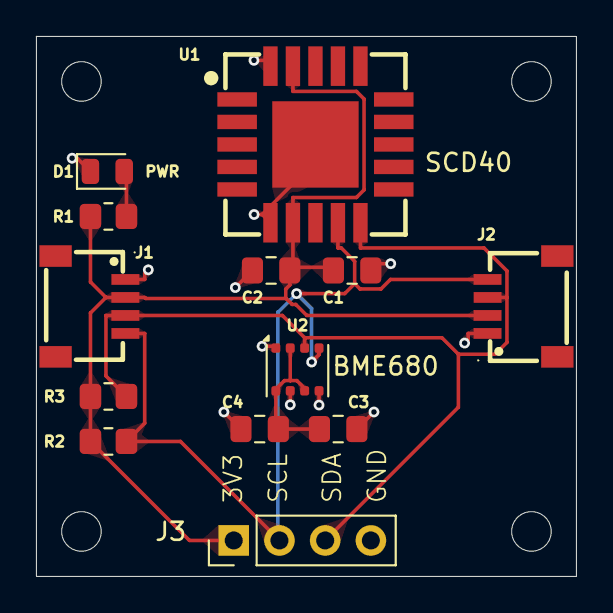
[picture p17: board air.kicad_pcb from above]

Board: 2 copper layers, 30.0 x 30.0 mm, 17 parts (0 on the bottom side), 6 nets.

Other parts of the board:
M1, M2, M3, M4: MountingHole_2.2mm_M2

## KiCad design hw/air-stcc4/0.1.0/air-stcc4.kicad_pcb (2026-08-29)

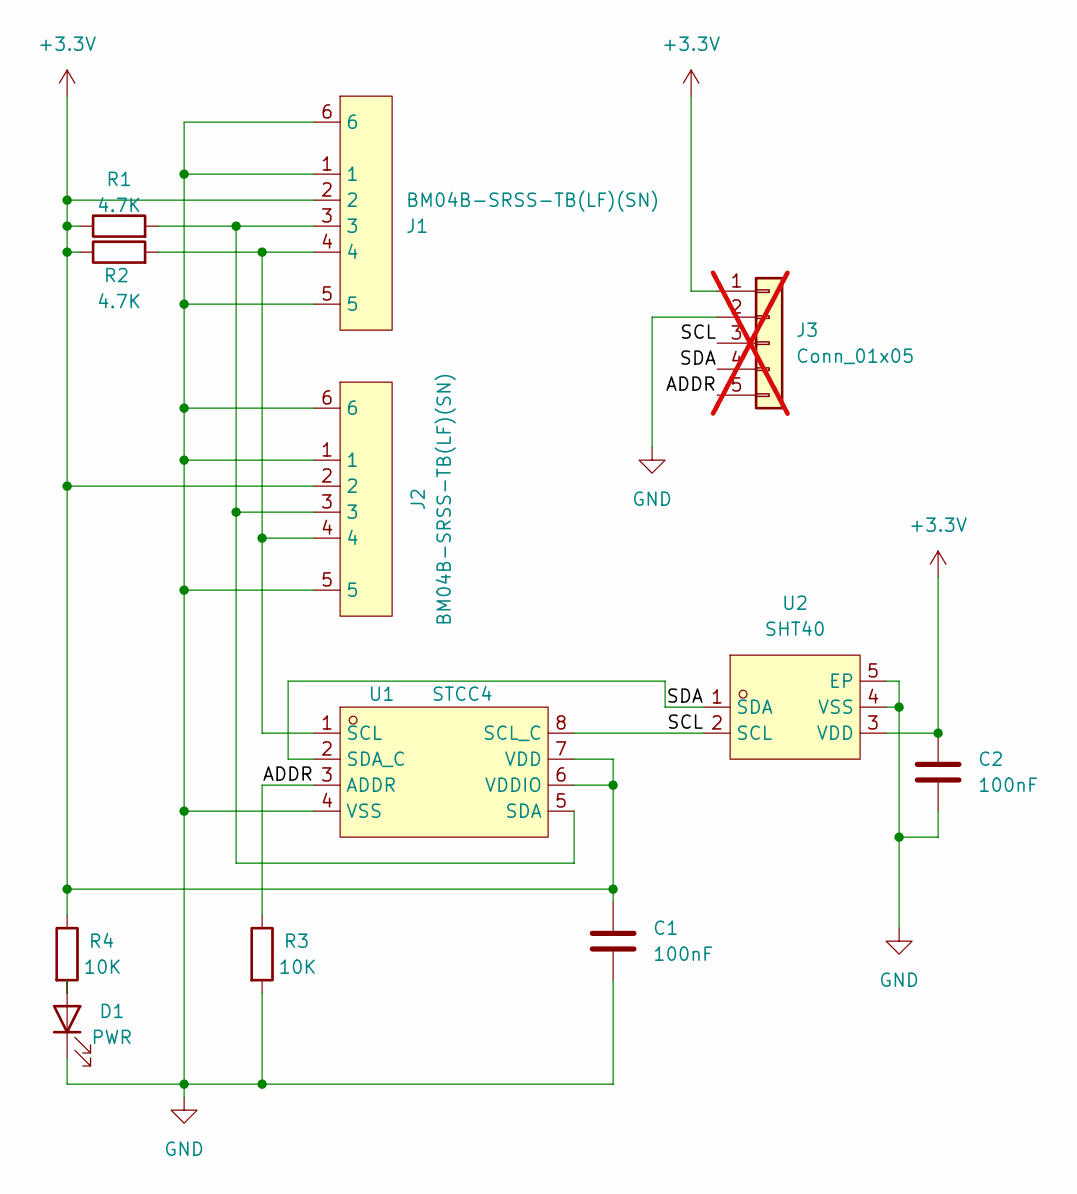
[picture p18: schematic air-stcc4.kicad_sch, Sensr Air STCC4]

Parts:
C1, C2: 100nF; C_0603_1608Metric_Pad1.08x0.95mm_HandSolder; MPN C14663
D1: PWR; LED_0603_1608Metric_Pad1.05x0.95mm_HandSolder; LCSC C2286
J1, J2: BM04B-SRSS-TB(LF)(SN); CONN-SMD_4P-P1.00_SM04B-SRSS-TB-LF-SN; LCSC Part C160404
J3: Conn_01x05; PinSocket_1x05_P2.54mm_Vertical; not fitted
R1, R2: 4.7K; R_0603_1608Metric_Pad0.98x0.95mm_HandSolder; MPN C23162
R3, R4: 10K; R_0603_1608Metric_Pad0.98x0.95mm_HandSolder; LCSC C25804
U1: STCC4; LAG-8_L4.0-W3.0-P1.15-TL; LCSC Part C49191471
U2: SHT40; DFN-4_L1.5-W1.5-P0.80-TL-EP; LCSC Part C7461861

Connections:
+3.3V: C1.1, C2.1, J1.2, J2.2, J3.1, R1.1, R2.1, R4.1, U1.6 (VDDIO), U1.7 (VDD), U2.3 (VDD)
/ADDR: J3.5, R3.1, U1.3 (ADDR)
/SCL: J3.3, U1.8 (SCL_C), U2.2 (SCL)
/SDA: J3.4, U1.2 (SDA_C), U2.1 (SDA)
GND: C1.2, C2.2, D1.1 (K), J1.1, J1.5, J1.6, J2.1, J2.5, J2.6, J3.2, R3.2, U1.4 (VSS), U2.4 (VSS), U2.5 (EP)
unnamed: D1.2 (A), R4.2
unnamed: J1.4, J2.4, R2.2, U1.1 (SCL)
unnamed: J1.3, J2.3, R1.2, U1.5 (SDA)

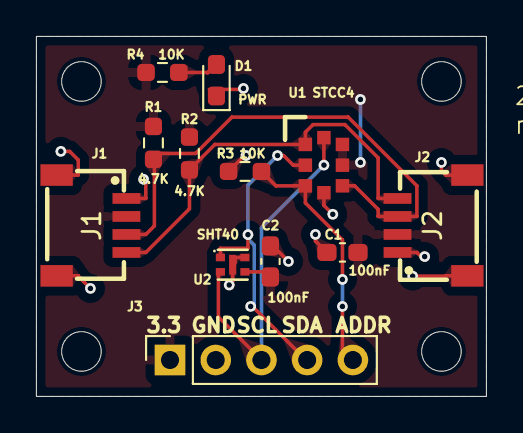
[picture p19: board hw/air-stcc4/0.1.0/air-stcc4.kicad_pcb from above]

Board: 2 copper layers, 25.0 x 20.0 mm, 16 parts (0 on the bottom side), 8 nets.

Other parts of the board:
M1, M2, M3, M4: MountingHole_2.2mm_M2

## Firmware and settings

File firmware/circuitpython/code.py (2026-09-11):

# SPDX-License-Identifier: MIT
#
# Test firmware for the sensr-air board (CircuitPython)
#
# Sensors under test (addresses as populated on hw/air-stcc4/0.4.0):
#   SGP41  (VOC/NOx, I2C 0x59) - adafruit_sgp41; boards up to 0.3.0 carry an
#          SGP40 instead, which is detected at runtime (see sgp4x_variant)
#   STCC4  (CO2,     I2C 0x64) - adafruit_stcc4
#   SFA40  (HCHO,    I2C 0x5D) - sfa40 (romkey/circuitpython-sfa40)
#   SHT40  (temp/RH) - not directly on the bus; it sits on the STCC4's private
#          I2C bus and is read through the STCC4
#   BMV080 (PM,      I2C 0x54) - NO CircuitPython driver exists (Bosch only
#          ships closed-source static libraries), so this test only verifies
#          that the BMV080 responds on the I2C bus.
#
# Expected output: a PASS/FAIL line for each sensor, then continuous readings.

import time

import board
import busio

import adafruit_stcc4
import sfa40

# Addresses on the sensr-air board
SGP4X_ADDR = 0x59
STCC4_ADDR = 0x64  # 0x65 if the ADDR line is pulled high
SFA40_ADDR = sfa40.SFA40_DEFAULT_ADDRESS  # 0x5D
BMV080_ADDR = 0x54

# SGP4x "Get Feature Set" (0x202F). The low 9 bits of the reply identify the
# part: the SGP40 measures VOC only, the SGP41 measures VOC and NOx. Both sit
# at 0x59 and answer the same serial-number command, so the feature set is the
# only way to tell them apart.
SGP4X_CMD_GET_FEATURESET = b"\x20\x2f"
SGP40_FEATURESET = 0x0020
SGP41_FEATURESET = 0x0040

READ_INTERVAL = 2  # seconds between readings
SGP41_CONDITIONING_S = 10  # NOx conditioning; must not exceed 10s


def get_i2c():
    """Use the board's STEMMA/Qwiic bus if present, else the default I2C pins."""
    try:
        return board.STEMMA_I2C()
    except AttributeError:
        return busio.I2C(board.SCL, board.SDA)


def scan_bus(i2c):
    while not i2c.try_lock():
        pass
    try:
        found = i2c.scan()
    finally:
        i2c.unlock()
    return found


def crc8(data):
    """Sensirion's CRC-8 (polynomial 0x31, init 0xFF)."""
    crc = 0xFF
    for byte in data:
        crc ^= byte
        for _ in range(8):
            crc = ((crc << 1) ^ 0x31) & 0xFF if crc & 0x80 else (crc << 1) & 0xFF
    return crc


def sgp4x_variant(i2c):
    """Return "SGP41", "SGP40", or None, by reading the sensor's feature set."""
    buf = bytearray(3)
    while not i2c.try_lock():
        pass
    try:
        i2c.writeto(SGP4X_ADDR, SGP4X_CMD_GET_FEATURESET)
        time.sleep(0.01)
        i2c.readfrom_into(SGP4X_ADDR, buf)
    except OSError:
        return None
    finally:
        i2c.unlock()

    if crc8(buf[0:2]) != buf[2]:
        return None

    featureset = ((buf[0] << 8) | buf[1]) & 0x1FF
    if featureset == SGP41_FEATURESET:
        return "SGP41"
    if featureset == SGP40_FEATURESET:
        return "SGP40"
    return None


def report(name, ok, detail=""):
    status = "PASS" if ok else "FAIL"
    print("[%s] %s %s" % (status, name, detail))
    return ok


print("sensr-air CircuitPython sensor test")
print("=" * 50)

i2c = get_i2c()

devices = scan_bus(i2c)
print("I2C scan:", " ".join(hex(d) for d in devices) or "no devices found")

variant = sgp4x_variant(i2c) if SGP4X_ADDR in devices else None
report(
    "SGP4x present (0x%02x)" % SGP4X_ADDR,
    variant is not None,
    "detected: %s" % (variant or "unknown"),
)
report("STCC4 present (0x%02x)" % STCC4_ADDR, STCC4_ADDR in devices)
report("SFA40 present (0x%02x)" % SFA40_ADDR, SFA40_ADDR in devices)
report(
    "BMV080 present (0x%02x)" % BMV080_ADDR,
    BMV080_ADDR in devices,
    "(presence check only - no CircuitPython driver)",
)
print()

# SGP41 (or SGP40 on boards up to 0.3.0)
sgp = None
if variant == "SGP41":
    try:
        from adafruit_sgp41.sgp41 import SGP41

        sgp = SGP41(i2c, address=SGP4X_ADDR)
        report("SGP41 self test", sgp.self_test_passed)
    except Exception as e:  # noqa: BLE001 - report and keep testing other sensors
        report("SGP41 init", False, repr(e))
        sgp = None
elif variant == "SGP40":
    try:
        import adafruit_sgp40

        # the driver verifies the SGP40's serial number during init
        sgp = adafruit_sgp40.SGP40(i2c, address=SGP4X_ADDR)
        report("SGP40 init", True)
    except Exception as e:  # noqa: BLE001
        report("SGP40 init", False, repr(e))
        sgp = None

# STCC4 (+ SHT40 via the STCC4's private I2C bus)
stcc4 = None
try:
    stcc4 = adafruit_stcc4.STCC4(i2c, address=STCC4_ADDR)
    serial = "".join("%02x" % b for b in stcc4.serial_number)
    report("STCC4 init", True, "serial: %s" % serial)
    result = stcc4.self_test()
    report("STCC4 self test", result == 0, "result: %d" % result)
    stcc4.continuous_measurement = True
except Exception as e:  # noqa: BLE001
    report("STCC4 init", False, repr(e))
    stcc4 = None

# SFA40 (formaldehyde, plus the humidity/temperature it compensates with).
# The constructor starts continuous measurement. The SFA40's self-test puts the
# sensor into a special mode for 5-6 minutes, so it is not run here - see the
# driver's sfa40_self_test.py example if you want to run it after assembly.
sfa = None
try:
    sfa = sfa40.SFA40(i2c, address=SFA40_ADDR)
    report("SFA40 init", True, "serial: %s" % sfa.serial_number_string)
except Exception as e:  # noqa: BLE001
    report("SFA40 init", False, repr(e))
    sfa = None

# The SGP41 needs up to 10s of NOx conditioning at 1Hz before its first real
# measurement. The SGP40 has no conditioning phase.
if variant == "SGP41" and sgp:
    print()
    print("Conditioning the SGP41 (%ds)..." % SGP41_CONDITIONING_S)
    for _ in range(SGP41_CONDITIONING_S):
        try:
            sgp.conditioning()
        except Exception as e:  # noqa: BLE001
            print("SGP41: conditioning error:", repr(e))
            break
        time.sleep(1)

print()
print("Continuous readings (every %ds):" % READ_INTERVAL)
print("-" * 50)

# let the STCC4 and SFA40 finish their first measurements
time.sleep(max(2, sfa40.FIRST_MEASUREMENT_DELAY))

while True:
    if sgp and variant == "SGP41":
        try:
            # the gas index algorithm expects 1Hz sampling and returns 0 for
            # both indices while it warms up (about 45s)
            voc_index, nox_index = sgp.measure_index()
            print(
                "SGP41:  raw VOC %d, raw NOx %d | VOC index %d, NOx index %d"
                % (sgp.raw_voc, sgp.raw_nox, voc_index, nox_index)
            )
        except Exception as e:  # noqa: BLE001
            print("SGP41:  read error:", repr(e))
    elif sgp:
        try:
            print("SGP40:  raw %d, VOC index %d" % (sgp.raw, sgp.measure_index()))
        except Exception as e:  # noqa: BLE001
            print("SGP40:  read error:", repr(e))

    if stcc4:
        try:
            # temperature/relative_humidity come from the SHT40, which the
            # STCC4 reads over its private I2C bus
            print(
                "STCC4:  CO2 %d ppm | SHT40: %.1f C, %.1f %%RH"
                % (stcc4.CO2, stcc4.temperature, stcc4.relative_humidity)
            )
        except Exception as e:  # noqa: BLE001
            print("STCC4:  read error:", repr(e))

    if sfa:
        try:
            m = sfa.measurement
            # the SFA40 measures its own humidity/temperature and uses them to
            # compensate the formaldehyde signal
            print(
                "SFA40:  HCHO %.1f ppb | %.1f C, %.1f %%RH%s"
                % (
                    m.formaldehyde,
                    m.temperature,
                    m.relative_humidity,
                    "" if sfa.within_specification else "  (warming up)",
                )
            )
        except Exception as e:  # noqa: BLE001
            print("SFA40:  read error:", repr(e))

    print()
    time.sleep(READ_INTERVAL)

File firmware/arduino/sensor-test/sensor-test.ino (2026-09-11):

// SPDX-License-Identifier: MIT
//
// Test firmware for the sensr-air board (Arduino / ESP32)
//
// Sensors under test (addresses as populated on hw/air-stcc4/0.4.0):
//   SGP41  (VOC/NOx, I2C 0x59) - Sensirion I2C SGP41 library; boards up to
//          0.3.0 carry an SGP40 instead, which is detected at runtime and
//          driven with the Sensirion I2C SGP40 library
//   STCC4  (CO2,     I2C 0x64) - Sensirion I2C STCC4 library
//   SFA40  (HCHO,    I2C 0x5D) - Sensirion I2C SFA4x library
//   SHT40  (temp/RH) - not directly on the bus; the STCC4 reads it over a
//          private second I2C bus and reports its values with each measurement
//   BMV080 (PM,      I2C 0x54) - DFRobot_BMV080 library (Bosch precompiled SDK;
//          ESP32/S2/S3 only)
//
// Target: ESP32-S3 (any ESP32 with Xtensa core works with the DFRobot library)
//
// Output: PASS/FAIL line per sensor on the serial console, then continuous
// readings every 2 seconds.

#include <Arduino.h>
#include <Wire.h>

#include <SensirionI2CSgp40.h>
#include <SensirionI2CSgp41.h>
#include <SensirionI2cSfa4x.h>
#include <SensirionI2cStcc4.h>
#include <DFRobot_BMV080.h>

// I2C pins; override for your dev board if needed
#ifndef I2C_SDA_PIN
#define I2C_SDA_PIN SDA
#endif
#ifndef I2C_SCL_PIN
#define I2C_SCL_PIN SCL
#endif

static const uint8_t SGP4X_ADDR = 0x59;
static const uint8_t STCC4_ADDR = STCC4_I2C_ADDR_64;  // 0x65 if ADDR pulled high
static const uint8_t SFA40_ADDR = SFA40_I2C_ADDR_5D;  // 0x5D
static const uint8_t BMV080_ADDR = 0x54;

// SGP4x "Get Feature Set" (0x202F). The low 9 bits of the reply identify the
// part: the SGP40 measures VOC only, the SGP41 measures VOC and NOx. Both sit
// at 0x59 and answer the same serial-number command, so the feature set is the
// only way to tell them apart.
static const uint16_t SGP4X_CMD_GET_FEATURESET = 0x202F;
static const uint16_t SGP40_FEATURESET = 0x0020;
static const uint16_t SGP41_FEATURESET = 0x0040;

static const uint32_t READ_INTERVAL_MS = 2000;
static const uint16_t SGP41_CONDITIONING_S = 10;  // must not exceed 10s

enum SgpVariant { SGP_UNKNOWN, SGP_40, SGP_41 };

SensirionI2CSgp40 sgp40;
SensirionI2CSgp41 sgp41;
SensirionI2cStcc4 stcc4;
SensirionI2cSfa4x sfa40;
DFRobot_BMV080_I2C bmv080(&Wire, BMV080_ADDR);

SgpVariant sgpVariant = SGP_UNKNOWN;
bool sgpOk = false;
bool stcc4Ok = false;
bool sfa40Ok = false;
bool bmv080Ok = false;
uint16_t conditioningLeft = SGP41_CONDITIONING_S;

static void report(const char* name, bool ok, const String& detail = "") {
  Serial.print(ok ? "[PASS] " : "[FAIL] ");
  Serial.print(name);
  if (detail.length()) {
    Serial.print(" ");
    Serial.print(detail);
  }
  Serial.println();
}

static bool i2cProbe(uint8_t address) {
  Wire.beginTransmission(address);
  return Wire.endTransmission() == 0;
}

static void i2cScan() {
  Serial.print("I2C scan:");
  bool found = false;
  for (uint8_t addr = 0x08; addr < 0x78; addr++) {
    if (i2cProbe(addr)) {
      Serial.printf(" 0x%02x", addr);
      found = true;
    }
  }
  if (!found) {
    Serial.print(" no devices found");
  }
  Serial.println();
}

// Sensirion's CRC-8 (polynomial 0x31, init 0xFF)
static uint8_t crc8(const uint8_t* data, size_t length) {
  uint8_t crc = 0xFF;
  for (size_t i = 0; i < length; i++) {
    crc ^= data[i];
    for (uint8_t bit = 0; bit < 8; bit++) {
      crc = (crc & 0x80) ? ((crc << 1) ^ 0x31) : (crc << 1);
    }
  }
  return crc;
}

static SgpVariant detectSgpVariant() {
  Wire.beginTransmission(SGP4X_ADDR);
  Wire.write(SGP4X_CMD_GET_FEATURESET >> 8);
  Wire.write(SGP4X_CMD_GET_FEATURESET & 0xFF);
  if (Wire.endTransmission() != 0) {
    return SGP_UNKNOWN;
  }
  delay(10);

  uint8_t reply[3] = {0};
  if (Wire.requestFrom(SGP4X_ADDR, (uint8_t)3) != 3) {
    return SGP_UNKNOWN;
  }
  for (uint8_t i = 0; i < 3; i++) {
    reply[i] = Wire.read();
  }
  if (crc8(reply, 2) != reply[2]) {
    return SGP_UNKNOWN;
  }

  uint16_t featureset = (((uint16_t)reply[0] << 8) | reply[1]) & 0x1FF;
  if (featureset == SGP41_FEATURESET) {
    return SGP_41;
  }
  if (featureset == SGP40_FEATURESET) {
    return SGP_40;
  }
  return SGP_UNKNOWN;
}

void setup() {
  Serial.begin(115200);
  delay(2000);

  Serial.println("sensr-air Arduino sensor test");
  Serial.println("==================================================");

  Wire.begin(I2C_SDA_PIN, I2C_SCL_PIN);

  i2cScan();

  sgpVariant = detectSgpVariant();
  report("SGP4x present (0x59)", sgpVariant != SGP_UNKNOWN,
         String("detected: ") + (sgpVariant == SGP_41   ? "SGP41"
                                 : sgpVariant == SGP_40 ? "SGP40"
                                                        : "unknown"));
  report("STCC4 present (0x64)", i2cProbe(STCC4_ADDR));
  report("SFA40 present (0x5D)", i2cProbe(SFA40_ADDR));
  report("BMV080 present (0x54)", i2cProbe(BMV080_ADDR));
  Serial.println();

  int16_t error = 0;

  // SGP41 (or SGP40 on boards up to 0.3.0)
  if (sgpVariant == SGP_41) {
    sgp41.begin(Wire);
    uint16_t serialNumber[3];
    error = sgp41.getSerialNumber(serialNumber);
    if (error == 0) {
      uint16_t testResult = 0;
      error = sgp41.executeSelfTest(testResult);
      // 0xD400 = all tests passed (see SGP41 datasheet)
      sgpOk = (error == 0) && (testResult == 0xD400);
      report("SGP41 self test", sgpOk,
             String("result: 0x") + String(testResult, HEX));
    } else {
      report("SGP41 init", false, String("error: ") + error);
    }
  } else if (sgpVariant == SGP_40) {
    sgp40.begin(Wire);
    uint16_t serialNumber[3];
    uint8_t serialNumberSize = 3;
    error = sgp40.getSerialNumber(serialNumber, serialNumberSize);
    if (error == 0) {
      uint16_t testResult = 0;
      error = sgp40.executeSelfTest(testResult);
      // 0xD400 = all tests passed (see SGP40 datasheet)
      sgpOk = (error == 0) && (testResult == 0xD400);
      report("SGP40 self test", sgpOk,
             String("result: 0x") + String(testResult, HEX));
    } else {
      report("SGP40 init", false, String("error: ") + error);
    }
  }

  // STCC4 (+ SHT40 read through the STCC4)
  stcc4.begin(Wire, STCC4_ADDR);
  uint32_t productId = 0;
  uint64_t stcc4Serial = 0;
  error = stcc4.getProductId(productId, stcc4Serial);
  if (error == 0) {
    bool testResult = false;
    error = stcc4.checkSelfTest(testResult);
    stcc4Ok = (error == 0) && testResult;
    report("STCC4 self test", stcc4Ok);
    error = stcc4.startContinuousMeasurement();
    if (error != 0) {
      stcc4Ok = false;
      report("STCC4 start measurement", false, String("error: ") + error);
    }
  } else {
    report("STCC4 init", false, String("error: ") + error);
  }
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

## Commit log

2026-09-11 doc and CI fixes
    [code.py, sensor-test.ino]
2026-09-11 CI: fix KiCAD checks, cache Arduino and ESPHome toolchains
    The KiCAD workflow ran kicad/kicad:9.0, but the 0.4.0 board and schematic
    are saved in KiCAD 10 format (20260206). The container could not load them,
    so ERC and DRC reported "Failed to load board"/"Failed to load schematic"
    and the current board was never actually checked. Bump the container to
    kicad/kicad:10.0.
    Exclude the two power_pin_not_driven ERC violations on 0.4.0 in the project
    file. kicad-cli honours stored exclusions unless --severity-exclusions is
    passed, which ci/kicad-check.sh does not, so manual ERC and CI now agree.
    Skip the retired hw/air board with .ci-kicad-ignore, mirroring its existing
    .ci-kilint-ignore. It fai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

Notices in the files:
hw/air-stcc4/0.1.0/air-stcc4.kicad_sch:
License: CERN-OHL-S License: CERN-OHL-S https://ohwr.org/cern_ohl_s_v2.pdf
